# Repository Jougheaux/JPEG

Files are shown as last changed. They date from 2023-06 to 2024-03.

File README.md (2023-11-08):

## JPEG
This is my(RPI's) brushless competition blaster with all the bells and whistles of the best.

## THIS BLASTER IS CURRENTLY IN AN OPEN BETA. THE FILES ARE FUNCTIONAL BUT NOT GUARANTEED TO BE FINAL.  DM me on discord (jougheaux) if you have questions.

## Pictures
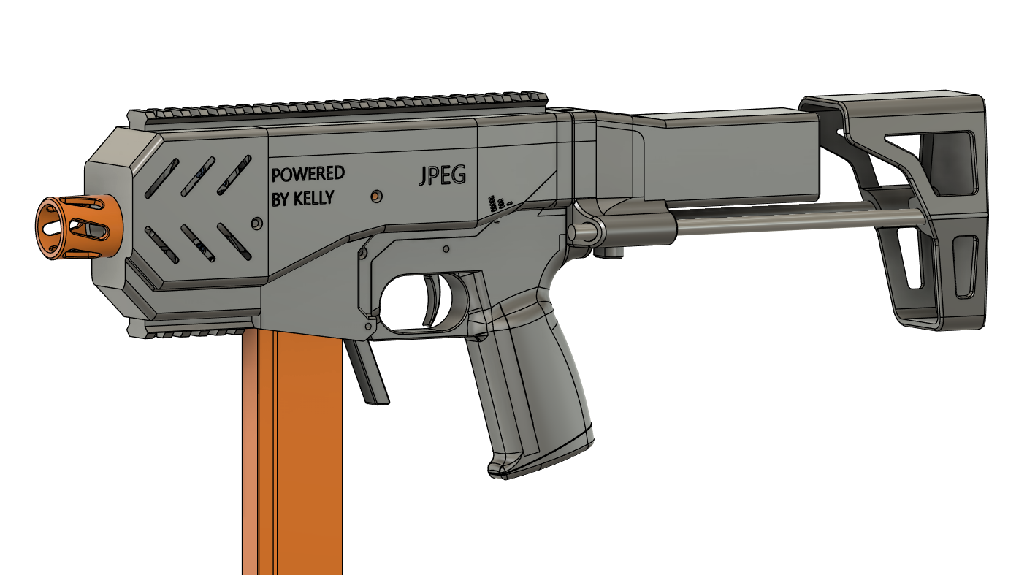
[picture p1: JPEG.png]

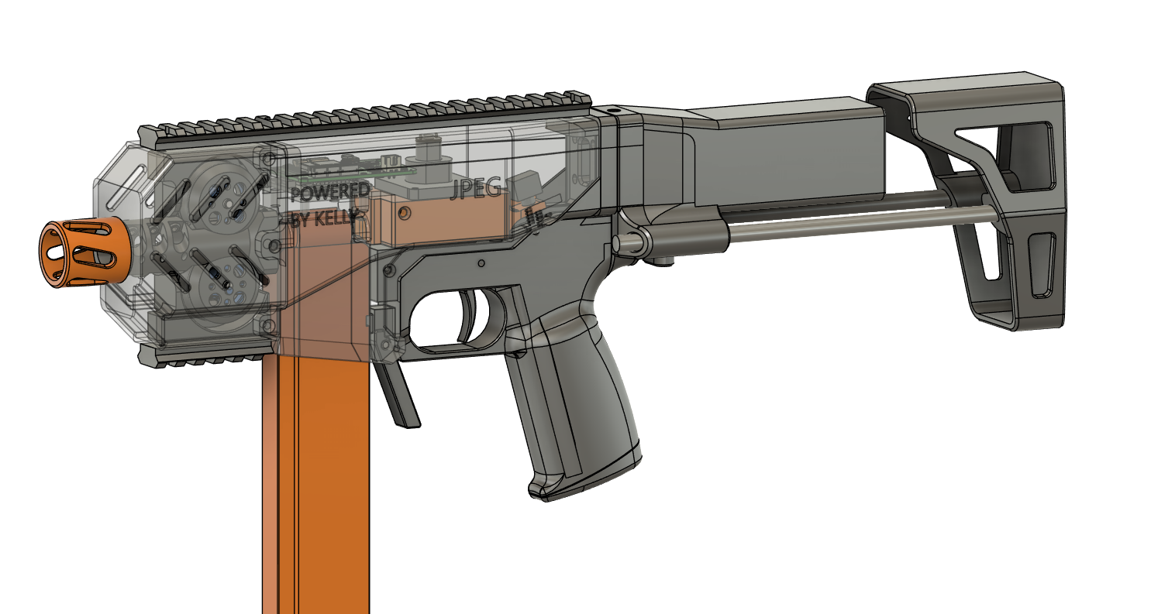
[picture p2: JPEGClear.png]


<details>
<summary>Updates (Click here)</summary>

 --------------------------------------
 - Koda support w. changes to magwell and mag retention
 - Elongated pusher for reliable feeding with 36mm workers
 - changed pusher construction (removed wedge)
 - removed feed lips from cage inner
 - \"adding speed holes to the shroud for maximum brrrrrrrrr and cooling"
 --------------------------------------
 - Stock Base & Battery Tray changed to have easier access to the battery
 - Lower changed to allow battery in grip and better printing
 - Grip bottom changed to allow battery in grip
 - Mag retention changed to have less slop
 - Magwell changed to no longer hold the selector switch
 - Pusher Body changed to hold the selector switch
 - Motor Housing changed for better wire routing
 - Wheels changed for smaller geometry
 - Cage became Cage Body and Cage Inner to allow for better printing
 - Muzzle is now threaded
 - Shroud has a slightly smaller opening in front
 - Added files for serialized grips and parametric cages/bcars
 --------------------------------------
 - adjusted heat set insert tolerance
 - uploaded wiring diagram (https://docs.google.com/document/d/1IgKOaXz1Wq1czSlrQZNBrS4rJvw-7m4BnzTXSQHMin8/edit)
--------------------------------------
- selectfire pictograph on magwell
- assembly guide added here (https://docs.google.com/document/d/1t8XXDXZycTl_3nRU9CUnI02HiXrD-tiSQikEmLgy0f4/edit)
--------------------------------------
- minor tweaks to: pusher body, wedge, stock base, stock mech plate, muzzle, shroud
- firmware now allows for 100, 130, and 200 fps options from the selector switch on boot up
- build guide coming soon
--------------------------------------
- v0.2 greatly reduces support material needed to print this blaster, v0.1.1 files are there for people who started printing
- Firmware is more reliable
- Print guide outlined on the second page of BOM (https://docs.google.com/spreadsheets/d/1kkiYsIlRcB7tAiH2ZU5NDMiAzAqcHJNqWwJKifN7Q3Q/edit#gid=0  )

</details>

## Features

- 193fps average, 207 max, standard deviation <10
- Brushless
- BCAR
- Selectfire
- Pre-wheel bearing guide
- Runs on KellyIndustries Dettlaff and Plusmotors
- Machined impeller wheels from Roboman

## Instructions
- [Print guide](https://docs.google.com/spreadsheets/d/1kkiYsIlRcB7tAiH2ZU5NDMiAzAqcHJNqWwJKifN7Q3Q/edit#gid=258203420)
- [Wiring guide](https://docs.google.com/document/d/1IgKOaXz1Wq1czSlrQZNBrS4rJvw-7m4BnzTXSQHMin8/edit)
- [Assembly guide](https://docs.google.com/document/d/1t8XXDXZycTl_3nRU9CUnI02HiXrD-tiSQikEmLgy0f4/edit)
- Grip bottom is serialized so ask me for available numbers (I'll probably make a spreadsheet to claim if there's enough people making them)  

## Hardware List  
Parts cost about $175, total cost higher if buying sets of screws  
[Hardware List](https://docs.google.com/spreadsheets/d/1kkiYsIlRcB7tAiH2ZU5NDMiAzAqcHJNqWwJKifN7Q3Q/edit#gid=0)  
Note: the worker stock is optional, however,  it is designed to only fit that stock.

## Thank Yous
I was the one working on the CAD, but this couldn't have been done without the efforts of the "RPI Nerf Industrial Complex" and members of the nerf community.
- Adrian Kelly/ KellyIndustries supplied their new [plus motors](https://kellyindustries.us/collections/flywheel-parts/products/plus-motor-brushless) and [Dettlaff](https://kellyindustries.us/collections/flywheel-parts/products/dettlaff-brushless-blaster-controller) along with creating the bruxa, which JPEG's pusher is based on (and the [Kellyindustries discord](https://discord.gg/gnhjt6QDAX) for helping troubleshoot)
- [Raymond Chien](https://www.linkedin.com/in/raymond-chien-1a0341229?original_referer=https%3A%2F%2Fwww.google.com%2F) for giving me parts and designs to work off of and for being a meme lord
- [Brad](https://thefactoryamsterdam.com/) [Roboman](https://roboman.net/) for giving me  bearings and being a cool dude
- [Gavinfuzzy](https://www.etsy.com/shop/GavinfuzzyCustoms) for giving me CAD for the worker stock from the SBL
- Mike Farley and Mathew Davis for helping guide aesthetics and design language
- RPI HVZ community for providing feedback and help

## To Do
- Solenoid version (pusher body can be repurposed to have a solenoid mount I just need to do CAD) (Eli Wu if you're reading this can I have one please)

## Licensing
<br />This work is licensed under a <a rel="license" href="http://creativecommons.org/licenses/by-nc-sa/4.0/">Creative Commons Attribution-NonCommercial-ShareAlike 4.0 International License</a>.

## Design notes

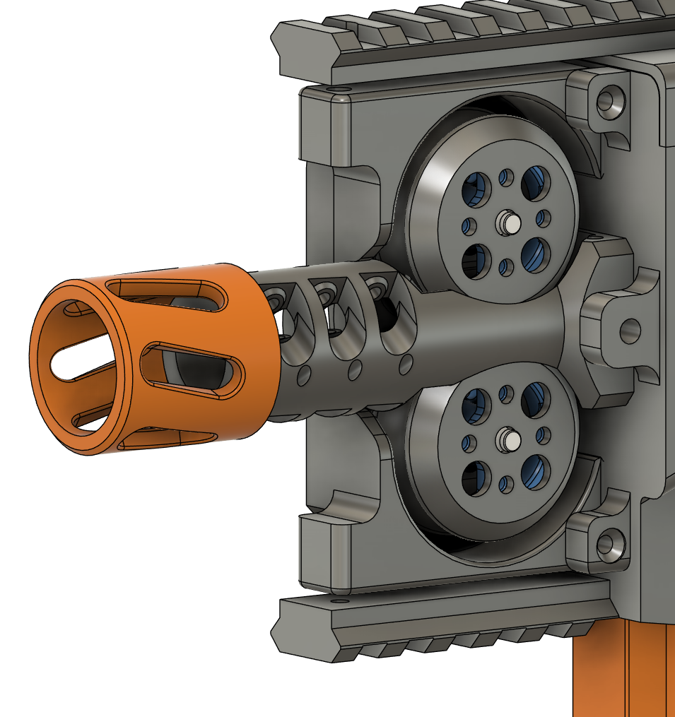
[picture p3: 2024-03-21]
JPEGCage.png

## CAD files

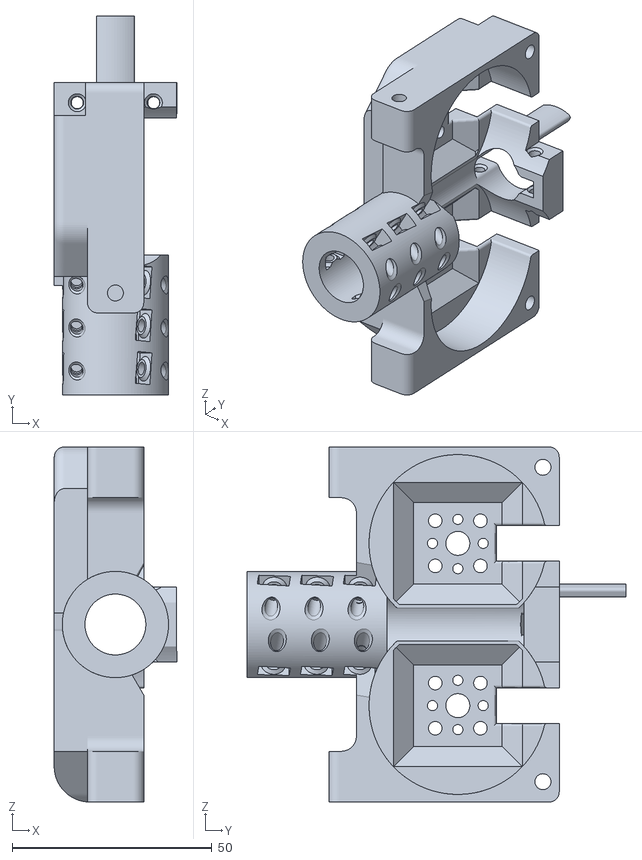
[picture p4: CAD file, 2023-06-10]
STLs/Cage/Cage.stl
30.7 x 94.9 x 88.9

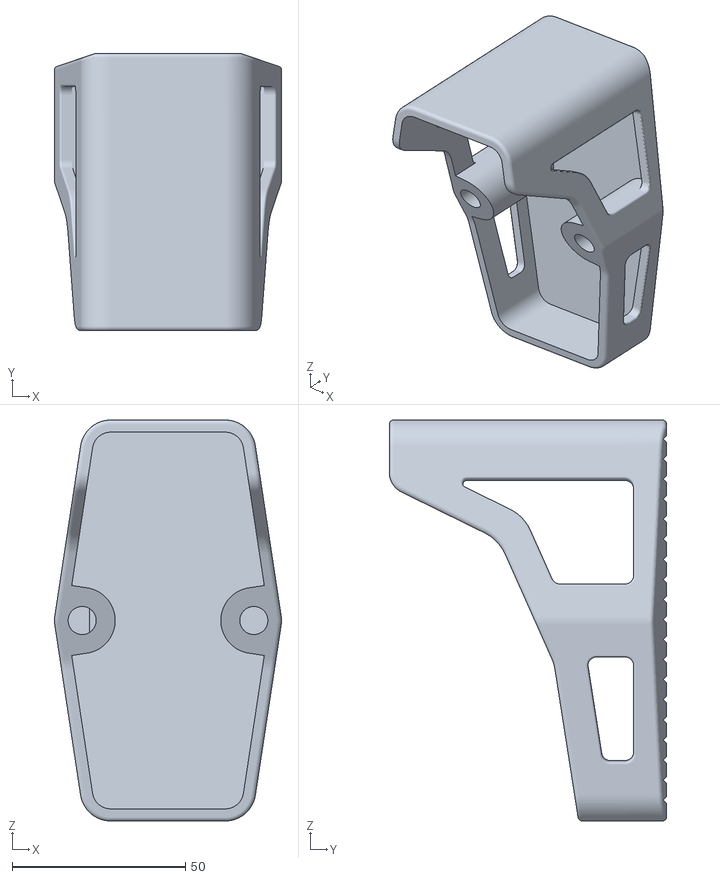
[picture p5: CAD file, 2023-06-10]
STLs/Stock/Stock.stl
65.5 x 80.0 x 115.6

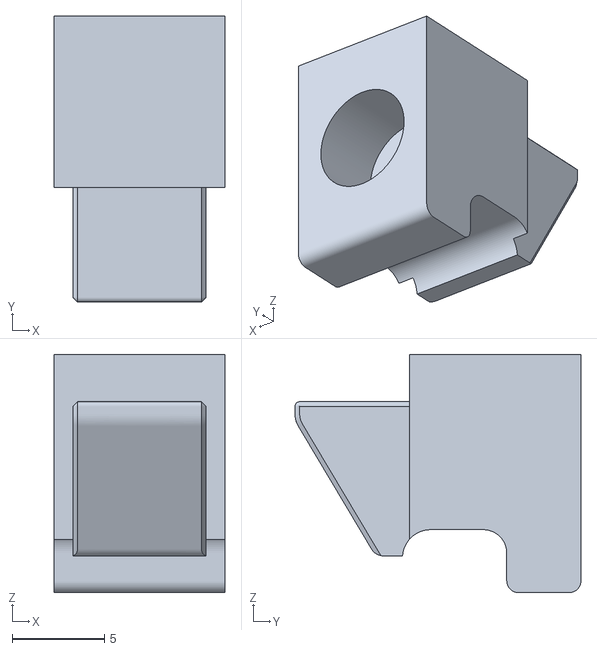
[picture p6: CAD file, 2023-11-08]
v0.4/STLs/Accesory/Mag Retention.stl
9.27 x 15.5 x 12.9

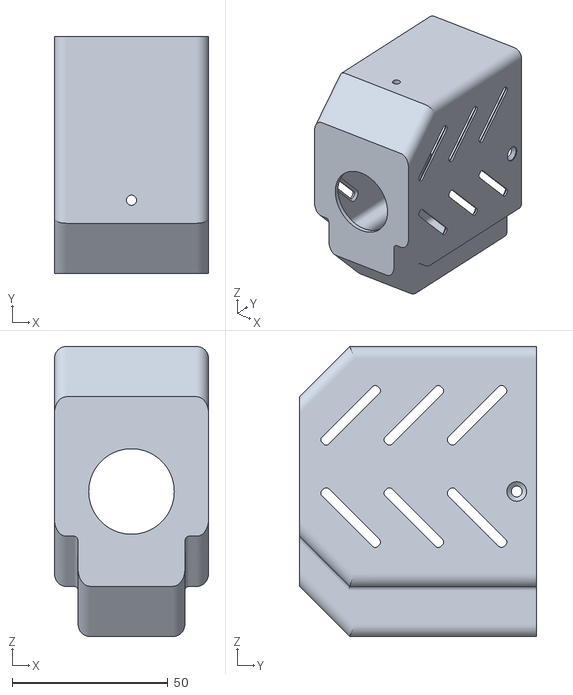
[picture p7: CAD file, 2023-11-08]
v0.4/STLs/Body/ShroudVented.stl
49.5 x 76.2 x 93.2

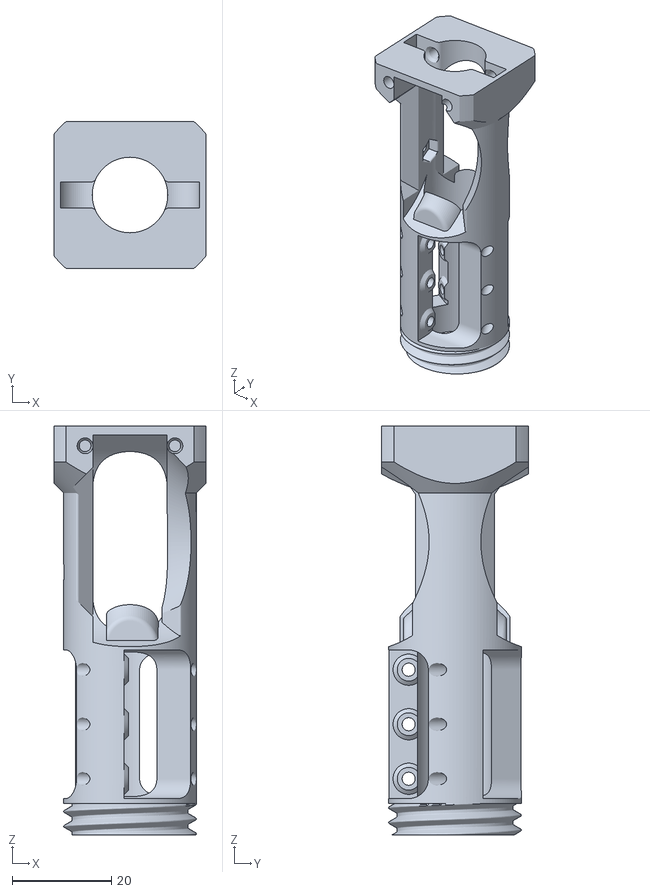
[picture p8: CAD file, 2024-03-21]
v0.4/STLs/Cage/CageInnersStraight.stl
30.7 x 29.6 x 82.5

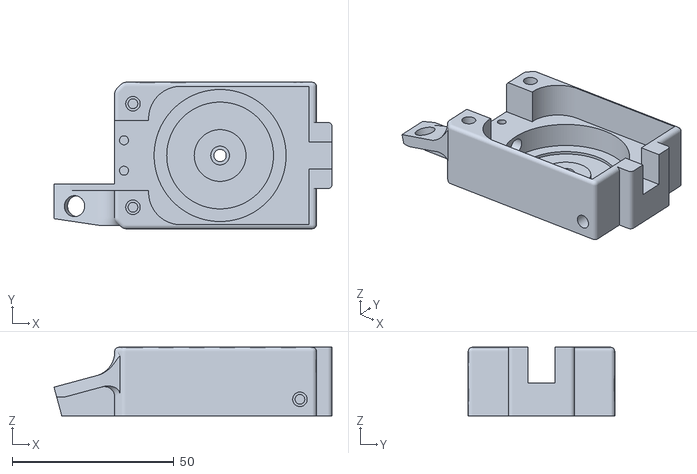
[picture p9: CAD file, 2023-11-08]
v0.4/STLs/Pusher/PusherBody.stl
85.9 x 45.3 x 21.2

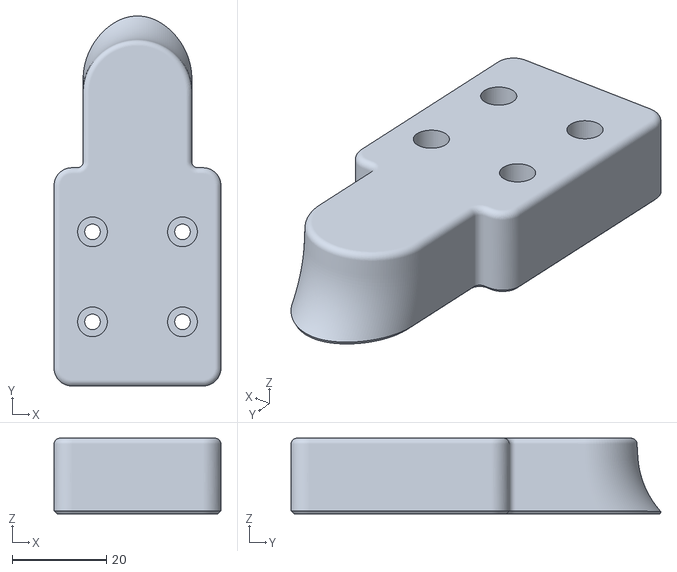
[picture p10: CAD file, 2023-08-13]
v0.4/STLs/Stock/EndCaps/Stock blank.stl
35.3 x 78.3 x 16.0

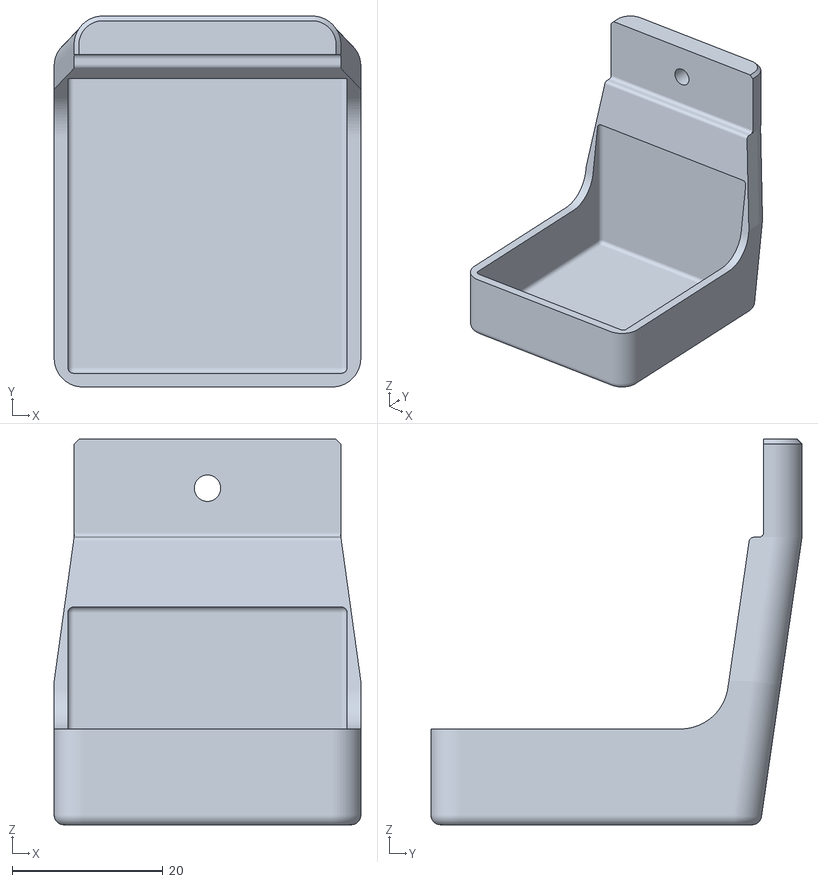
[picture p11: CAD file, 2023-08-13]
v0.4/STLs/Stock/WorkerBatteryStock/BatteryTrayFiller.stl
40.6 x 49.2 x 51.1

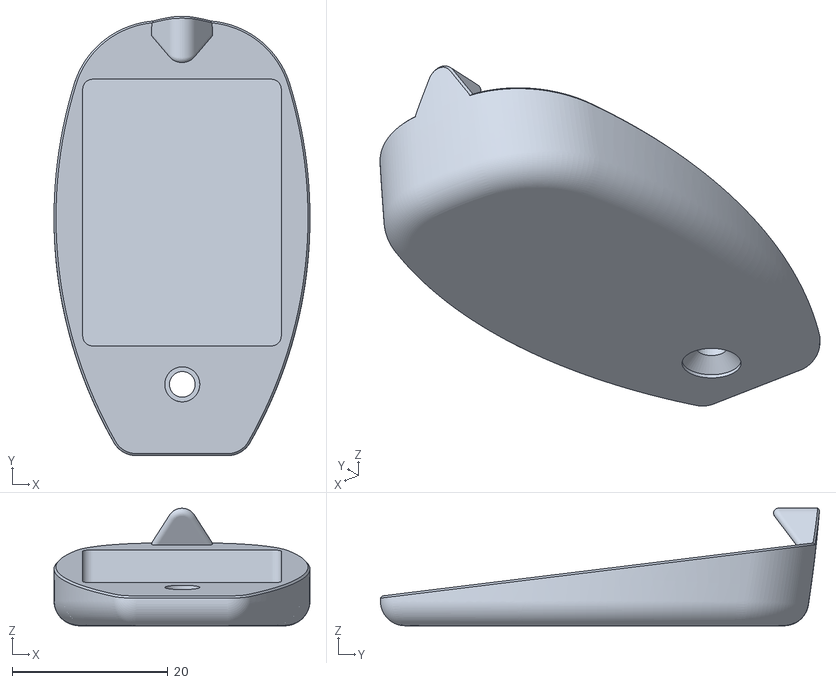
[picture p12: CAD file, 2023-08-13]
v0.4/STLs/Accesory/GripBottomBlank.stl
32.9 x 56.4 x 15.1

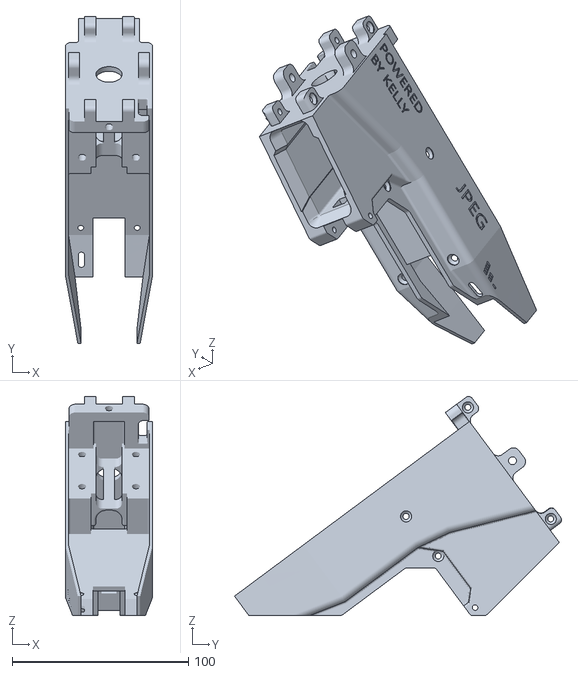
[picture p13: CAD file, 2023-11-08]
v0.4/STLs/Body/Magwell.stl
49.5 x 185.3 x 124.1

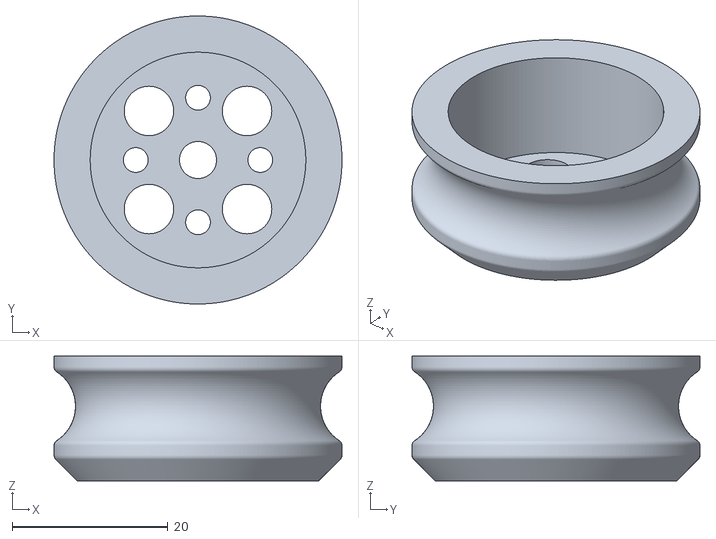
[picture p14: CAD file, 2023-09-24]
v0.4/STLs/Cage/7mmWheel.1.stl
37.0 x 37.0 x 16.0

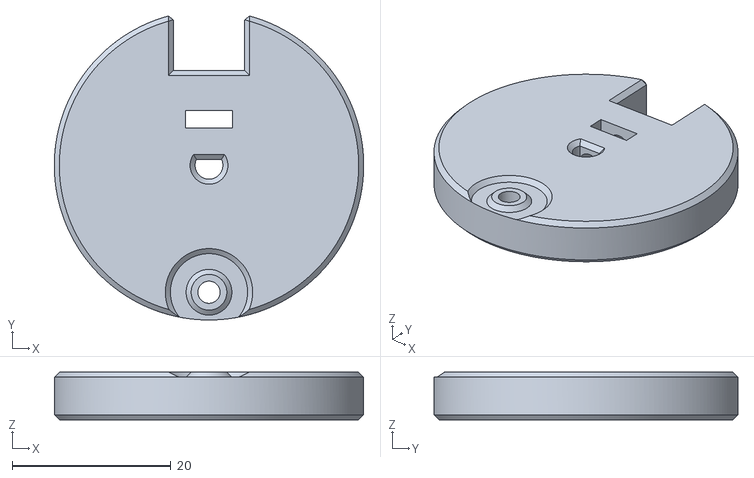
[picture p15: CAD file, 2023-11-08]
v0.4/STLs/Pusher/PusherWheel.stl
39.0 x 38.3 x 6.00

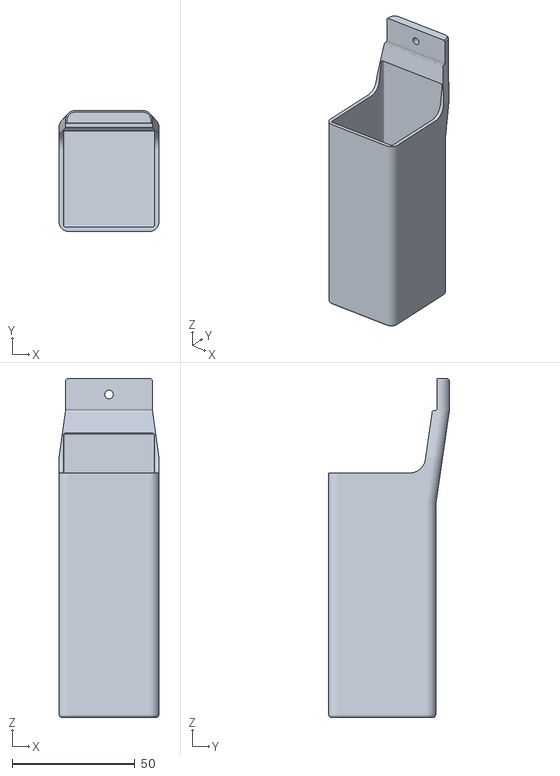
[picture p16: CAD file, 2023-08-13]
v0.4/STLs/Stock/WorkerBatteryStock/BatteryTray 95mm.stl
40.6 x 49.2 x 137.8

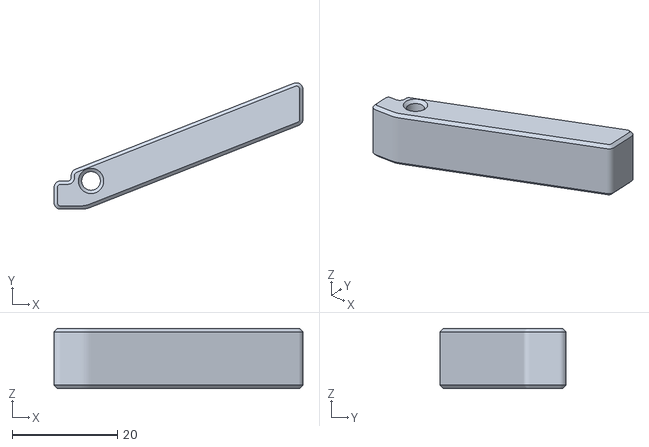
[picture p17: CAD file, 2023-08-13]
v0.4/STLs/Accesory/Mag Release.stl
47.3 x 24.0 x 11.4

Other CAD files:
v0.4/STLs/Body/Lower.stl
v0.4/STLs/Cage/CageBody.stl
v0.4/STLs/Pusher/MotorHousing.stl
v0.4/STLs/Stock/WorkerBatteryStock/StockBaseWorker.stl
STLs/Body/Lower.stl
STLs/Body/Magwell.stl
STLs/Cage/7mmWheel.stl
STLs/Cage/7mmWheelSLS.stl
v0.2/STLs/Body/Lower.stl
v0.2/STLs/Body/Magwell.stl
v0.2/STLs/Cage/Cage.stl
v0.4/STLs/Accesory/BottomPicRail.stl
v0.4/STLs/Accesory/TopPicRail.stl
v0.4/STLs/Accesory/Trigger.stl
v0.4/STLs/Body/TopCover.stl
v0.4/STLs/Cage/7mmWheel.stl
v0.4/STLs/Cage/7mmWheelSLS.stl
v0.4/STLs/Cage/CageInner5deg.stl
v0.4/STLs/Pusher/Pusher.stl
v0.4/STLs/Stock/WorkerBatteryStock/StockMechPlate.stl

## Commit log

2023-06-10 STL files for JPEG
    [7mmWheel.stl, 7mmWheelSLS.stl, Battery Cover.stl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]
2023-06-10 Oriented STLs
    [Battery Cover.stl, BottomPicRail.stl, GripBottomBLANK.stl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]
2023-06-28 Updated to new dettlaff firmware
    [CONFIGURATION.h]
2023-06-29 New file set with much fewer supports needed
    [7mmWheel.stl, 7mmWheelSLS.stl, Battery Cover.stl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]
2023-07-11 Minor DfA tweaks & code updates
    [CONFIGURATION.h, KellyWedge.stl, Muzzle.stl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]
2023-07-12 Update Battery Cover.stl
    [Battery Cover.stl]
2023-07-12 Longer StockBase for battery clearance
    [StockBase.stl]
2023-07-18 Select fire pictograph
    [Magwell.stl]
2023-07-20 Minor tolerance changes
    [CONFIGURATION.h, PusherBody.stl, StockBase.stl]
2023-07-21 More battery clearance in StockBase and new BatteryCover
    [Battery Cover.stl, StockBase.stl]
2023-08-13 v0.3 files for JPEG
    [7mmWheel.stl, 7mmWheelSLS.stl, Battery Cover.stl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]
2023-09-24 Straight BCAR and tighter wheels
    [7mmWheel.1.stl, CageInnersStraight.stl]
2023-09-24 Lightweight pusher wheel alternative
    [PusherStickBETA.stl]
2023-11-08 JPEG v0.4
    [7mmWheel.1.stl, 7mmWheel.stl, 7mmWheelSLS.stl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]
2024-04-16 Moved files
    [Shroud.stl, ShroudVented.stl]
